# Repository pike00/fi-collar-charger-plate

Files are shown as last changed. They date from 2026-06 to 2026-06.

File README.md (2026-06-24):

---
title: "Fi collar charger plate"
description: "A 3D-printed Decora outlet faceplate that holds two Fi Series 3 dog-collar charging bases in flanking cradles, charges the collars in place, keeps the outlet usable, and swallows t…"
date: 2026-06-10
version: v2.2
tags: [pet, mounting, electronics]
material: PETG / PLA
print: { layer_height: 0.2mm, infill: 25%, supports: false }
license: CC-BY-NC-4.0
showcase: false
source: private
---

# Fi collar charger plate

A 3D-printed **Decora outlet faceplate** that holds **two Fi Series 3 dog-collar
charging bases** in flanking cradles, charges the collars in place, keeps the
outlet usable, and swallows the cables inside the cradle bodies.

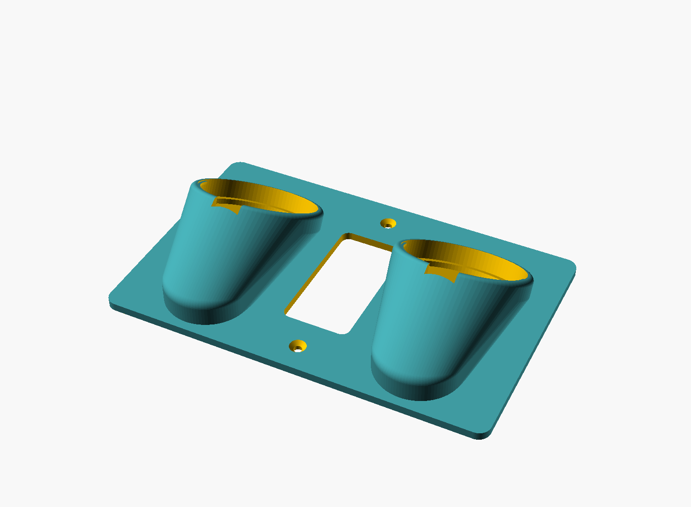
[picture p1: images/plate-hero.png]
hero


## What it mates with

- **Outlet:** standard single-gang **Decora / rocker** receptacle. Mounts with
  the existing two **6-32** strap screws, **3.812" (96.85 mm)** center-to-center.
  The Decora opening is left clear so the receptacle stays usable.
- **Chargers:** two round **Fi Series 3 charging bases** (the black pucks). The
  base is **magnetic** — the collar's module snaps onto the top face and is held
  by magnet while it charges. The holder grips the *base*; the base does the
  charging and collar retention. Powered by a micro-USB cable out of each base.
- **Power:** a small **USB wall brick plugs into this same outlet** (the opening
  is left clear for it — on a duplex receptacle one socket can stay free). Both
  base cables run inward to that brick, so there's no cable run down the wall.

## How it works

Each cradle is **one seamless hulled form**: a tilted cup blended smoothly into
a rounded foot pad on the plate — no flares or stuck-on boxes; the hull surface
itself is the blend. The cup leans back (`cradle_tilt`, default 30°) so the
charging face aims up-and-out; the magnetic base plus a thin lip keep everything
seated. The collar band drapes down the front.

**Geometry constraint (why 30° and why the cup floats):** a wide puck tilted
near a wall would physically extend *behind* the wall plane — at 45° a 67 mm
puck needs its rear edge ~22 mm inside the wall. The model auto-derives
`cup_lift` from the tilt so the entire recess clears the wall plane (+1 mm).
Versions before v1.6 missed this; their recesses were sheared off at the wall
and a real puck could never have seated. Raising `cradle_tilt` is allowed but
automatically grows the prow (45° → ~62 mm stick-out; 30° → ~48 mm).

**Retaining lip:** a thin inward **lip** (`lip_in`, default 1.3 mm) on the lower
half of the recess rim, with a gap at the bottom aligned with the cable slot.
Drop the puck in from the top; the lip catches its rim so it can't slide out.

**Cables / where they go:** the puck's micro-USB plug rides down a **slot in the
cup's lower wall** (`notch_w`) as the puck seats. The slot continues inside the
cradle body into a **hidden cable cavity** (`cav_*`) — coil the excess in there.
The tail exits a small **mouth on the cradle's inner side** and runs along a
shallow **groove** in the plate face to the USB brick in the outlet. Use a short
cable (6–12") so the cavity isn't overstuffed.

The mounting face is dead flat (everything is clipped at the wall plane), so it
sits flush on the outlet.

## Dimensions are ESTIMATED (Fi doesn't publish them)

Fi publishes no specs for the bare base puck — only the retail box
(170 × 110 × 63 mm). The values below are an **estimate** from product photos +
the box size, set at the top of
[src/fi-collar-charger-plate.scad](src/fi-collar-charger-plate.scad). The fit is
forgiving (magnetic retention + generous clearance), but a 20-second ruler check
of the real puck lets you tighten it to a true snug fit:

| Parameter | Meaning | Value (estimate) |
|---|---|---|
| `base_dia` | outer diameter of the round Fi base | **67 mm — estimate**  |
| `base_thick` | puck thickness / height | **13 mm — estimate**  |
| `base_clear` | radial fit clearance | 1.0 mm (generous) |
| `cradle_tilt`| base face angle from vertical | 30° (lift auto-derived) |

Re-export after editing: `just build` (or override headless, e.g.
`openscad -D 'base_dia=63' -D 'base_clear=0.5' -o out.stl src/...scad`).

## Size note (the honest trade-off)

A face-up puck held near a wall **inherently sticks out** — there is no way to
charge a collar face-up against a wall without a shelf-like protrusion, and the
wall-clearance constraint above makes the minimum protrusion a function of tilt.
At the 67 mm estimated size the plate comes out **~210 × 123 × 4 mm (8.3 × 4.8")**
and the cradles stand **~48 mm proud** at the rim front (30° tilt). Levers:

- **Smaller real `base_dia`** — quite possible; 67 mm is an estimate. Shrinks
  both the plate and the required lift.
- **Lower `cradle_tilt`** — flatter to the wall, smaller prow (magnetic
  retention means the collar stays on even at a low tilt).
- **Switch layout to stacked** (cups above the opening, not flanking) — a much
  narrower plate (~93 mm wide: cup + edge margins). This is a code change, not
  a parameter.

## Print settings (suggested — update after first print)

- Material: PETG or PLA+ (near an outlet; PETG tolerates warmth better).
- Layer height: 0.2 mm. Walls: 3+ perimeters. Infill: 15–25%. Solid model
  volume is ~280 cm³ (measured via trimesh) — the hulled cradles are chunky, so
  filament use is driven by infill; trust the slicer's estimate.
- **Orientation:** plate back (wall side) flat on the bed; cups face up. The
  hull prow is a smooth ~45–60° overhang — self-supporting. The hidden cable
  cavity ceiling bridges ~30 mm; droop in there is invisible. The cup rim's
  upper arc may want a touch of support at high `cradle_tilt`.
- Screws: reuse the outlet's existing 6-32 screws; `screw_clear`/`screw_head`
  are sized for a flat-head countersink on the front face.

## Build

```
just build      # export export/fi-collar-charger-plate.stl (high $fn)
just preview    # re-render images/*.png (needs xvfb on this headless host)
just dims       # print derived plate size / cup bore without exporting
just clean      # remove generated STL
```

BOSL2 is pulled from `~/.local/share/OpenSCAD/libraries` via `OPENSCADPATH`
(wired into the justfile).

Inspection renders: `-D section=1` slices a cup (YZ); `-D section=2` slices the
cable cavity (XZ).

## Status

**v1.6 — geometry rebuilt: each cradle is one hulled seamless form (cup + foot
pad), the cable cup is now an internal hidden cavity with an inner exit mouth,
and the wall-intersection flaw was found and fixed (`cup_lift` auto-derived so
the recess actually clears the wall; tilt default now 30°). Verified by a
3-agent adversarial audit (numeric transform recomputation + trimesh probes of
the STL + render inspection): recess clears the wall by 0.87 mm, chute→cavity
aperture 175 mm², mouth exits to open air, mesh watertight. The audit caught and
this version fixes: a lip strap bridging the cable slot (center=true cutter
bug), 0.16 mm cavity-corner membranes (pad roundover now buried in the plate),
a mouth-exit ledge, floating groove starts, and a 1 mm groove web (now 2 mm).**
Not yet printed; a ruler check of the real puck would let you tighten the fit.
See the table above.

Earlier: v1.5 flare experiment (superseded — the flare never matched the tilted
footprint and looked lumpy), v1.4 hollow-shell fix, v1.3 bins + lip, v1.2 inward
routing, v1.1 estimated dims, v1 first cut.

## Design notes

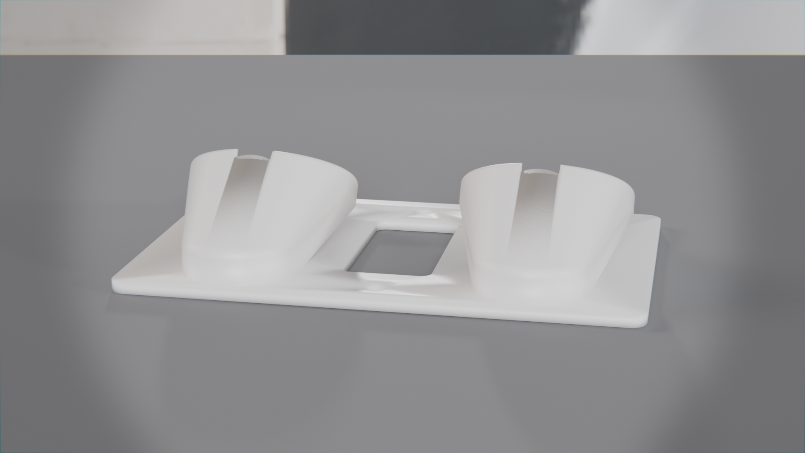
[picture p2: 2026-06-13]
images/blender-hero.png

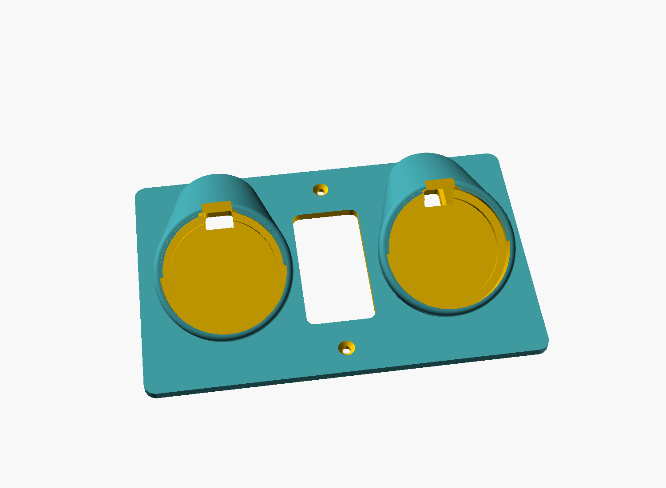
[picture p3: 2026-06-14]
images/plate-topdown.png

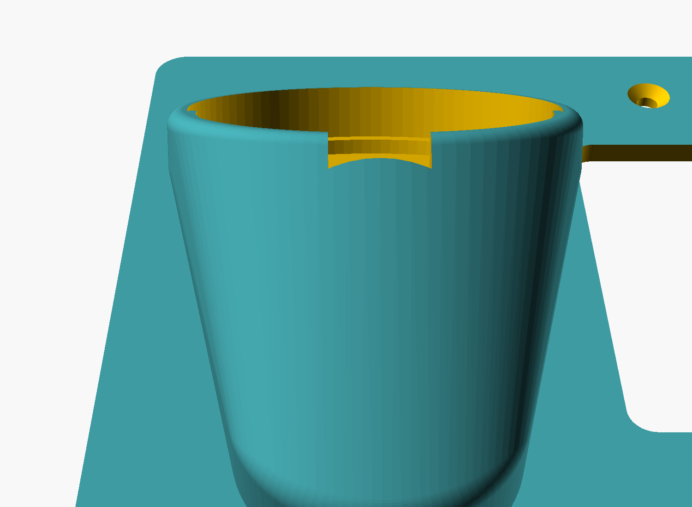
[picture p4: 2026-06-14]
images/zoom-cup.png

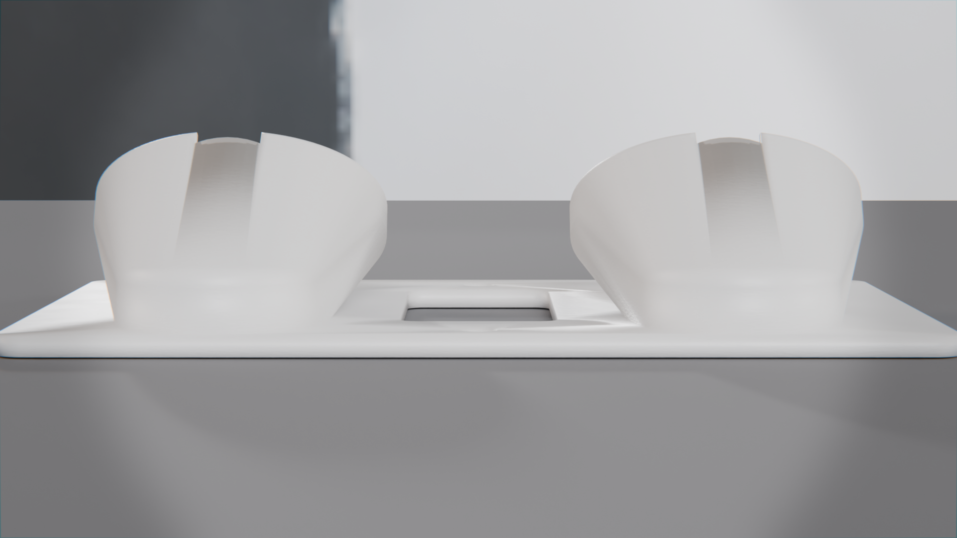
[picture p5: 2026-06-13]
images/blender-front.png

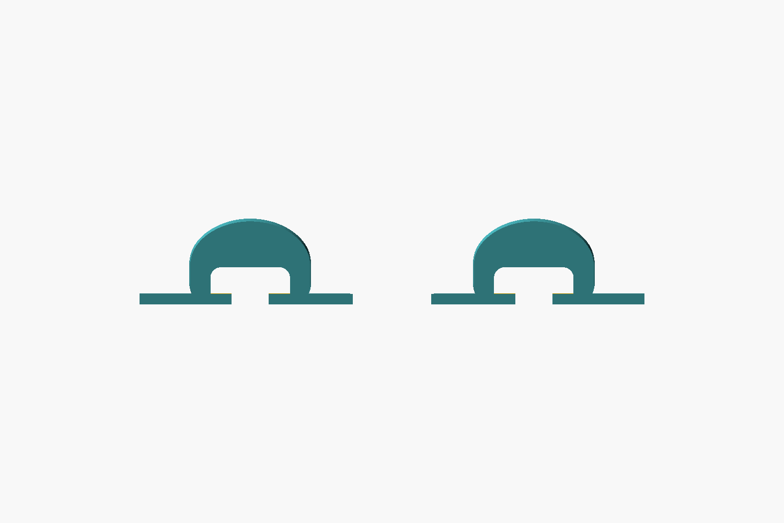
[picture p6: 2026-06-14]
images/section-cavity.png

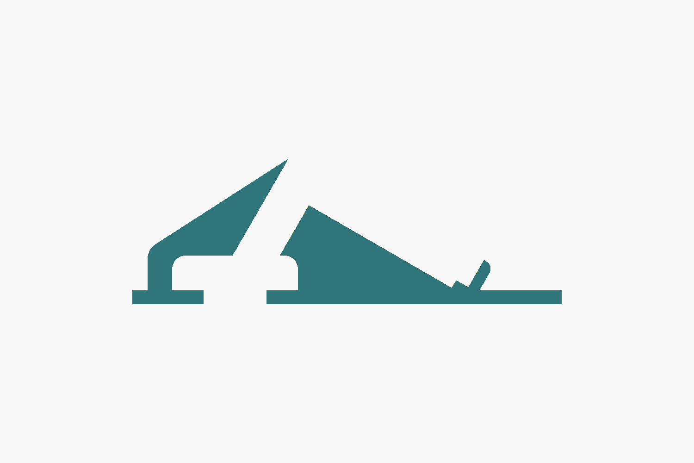
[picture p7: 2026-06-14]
images/section-cup.png

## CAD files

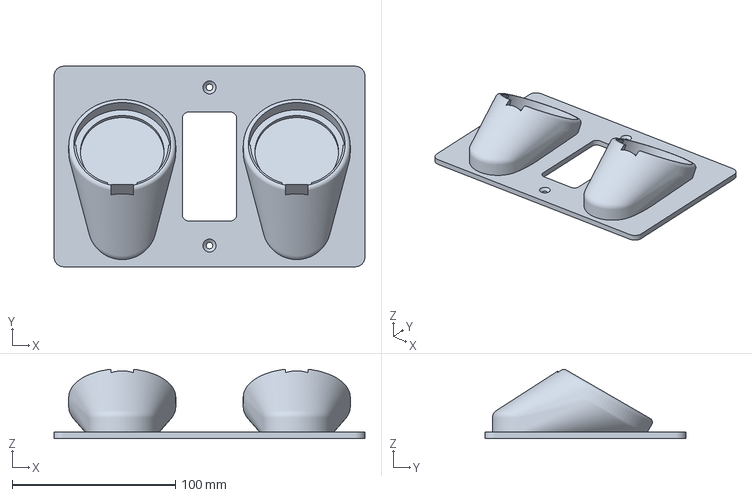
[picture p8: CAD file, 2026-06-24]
export/fi-collar-charger-plate.3mf
190.5 x 122.8 x 42.5 mm

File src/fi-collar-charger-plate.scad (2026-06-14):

// =============================================================================
// Fi collar charger plate — flanking cradles on a Decora outlet faceplate
// -----------------------------------------------------------------------------
// Mounts to a standard single-gang DECORA receptacle using the two 6-32 strap
// screws (3.812" / 96.85 mm vertical c-c). The Decora opening stays clear so a
// small USB brick can plug into the outlet. Two cradles flank the opening; each
// is ONE seamless hulled form: a tilted cup (charging face up-and-out) blending
// smoothly into a rounded base pad on the plate. The Fi base puck drops into the
// cup and a thin lip captures its rim. The puck's cable rides down a slot in
// the cup's lower wall into a HOLLOW CAVITY inside the cradle body, then exits
// through a slot in the plate BACK FACE into the wall box — no groove across
// the plate front, no sharp inner-mouth bend (~30° curve max from cup axis).
//
// The holder grips the BASE; the base (magnetic) does the charging + collar
// retention. Only fit-critical inputs are the puck's own dimensions.
//
// Build:   just build        (STL)     |  Preview: just preview  (PNG)
// Override any param headless:  openscad -D 'base_dia=58.2' -o out.stl <src>
// Inspect: -D section=1 (YZ slice through a cup), -D section=2 (XZ slice
//          through the cable cavity).
// =============================================================================

include <BOSL2/std.scad>

/* [Fi base puck — measured with calipers] */
// Outer diameter of the round Fi Series 3 base puck (mm). Measured: 58.2 mm.
base_dia      = 58.2;
// Puck thickness / height (mm). Measured: 11 mm.
base_thick    = 11;

/* [Fit] */
// Radial clearance around the puck (mm). Tightened to 0.5 now that we have
// a real measurement; adjust ±0.2 for printer tolerance.
base_clear    = 0.5;

/* [Cradle] */
// Base FACE angle from VERTICAL: 0 = faces straight out from wall, 90 = faces
// straight up. NOTE: tilting a wide puck near a wall forces the cup outward —
// the model auto-derives `cup_lift` so the recess fully clears the wall plane
// (at 45 deg the prow would stick out ~62 mm; 30 deg lands at ~48 mm).
cradle_tilt   = 30;      // deg
// How deep the puck sits into the cup. Keep < base_thick so the charging face
// stays exposed for the collar.
cup_depth     = 9;       // mm
cradle_wall   = 3.2;     // mm  cup side wall
cup_round     = 2.5;     // mm  rounding on the cup body edges (soft rim)

/* [Cup ledge — ring that the puck rim rests on; cup interior is open above and below] */
ledge_h       = 2.5;     // mm  ledge ring height
ledge_w       = 4.0;     // mm  ledge ring radial width (inward from cup inner wall)

/* [Base pad — the cradle's foot; the hull from cup to pad IS the seamless blend] */
pad_d         = 42;      // mm  pad diameter on the plate
pad_y         = -36;     // mm  pad center, below the cup (toward plate bottom)
pad_h         = 14;      // mm  pad height
pad_round     = 5;       // mm  pad edge rounding

/* [Charger retaining lip — thin catch over the puck rim] */
lip_in        = 1.3;     // mm  inward overhang over the puck rim
lip_h         = 1.4;     // mm  lip thickness (down from the cup rim)
lip_gap_w     = 18;      // mm  gap in the lip at the bottom (puck/cable slot)

/* [Cable — slot down cup wall into cavity, exits through plate BACK face] */
notch_w       = 14;      // mm  slot width in the cup's lower wall (plug rides down)
cav_w         = 30;      // mm  internal cable cavity width  (x)
cav_len       = 36;      // mm  internal cable cavity length (y)
cav_h         = 10;      // mm  cavity height above the plate front
mouth_w       = 14;      // mm  back-plate exit slot width (x); cable exits rearward

/* [Decora plate] */
plate_th      = 4.0;     // mm  faceplate slab thickness
plate_corner  = 6;       // mm  rounded outer corners
opening_w     = 33.3;    // mm  Decora opening width  (1.31")
opening_h     = 66.8;    // mm  Decora opening height (2.63")
opening_r     = 4;       // mm  opening corner radius
screw_spacing = 96.85;   // mm  6-32 strap screw c-c, vertical (3.812")
screw_clear   = 4.0;     // mm  6-32 shank clearance hole
screw_head    = 8.0;     // mm  countersink head diameter (flat-head)
edge_margin   = 9;       // mm  plate material around the cradles/screws
gap           = 4;       // mm  clearance between Decora opening and a cradle

/* [Quality] */
$fn           = 48;      // bump to 96+ for the final export

// ---- derived ----------------------------------------------------------------
cup_id        = base_dia + 2*base_clear;          // cup inner bore
cup_od        = cup_id + 2*cradle_wall;           // cup outer
cup_h         = cup_depth + ledge_h;              // cup total height
// Lift the cup out along its own axis until the ledge's rear edge sits
// in FRONT of the wall plane (+1 mm along the axis, ~0.87 mm normal to the
// wall). Without this, a tilted wide puck physically intersects the wall — the
// flaw in every version before v1.6.
cup_lift      = max(0, (cup_id/2)*tan(cradle_tilt) - ledge_h + 1);
assert(cup_depth < base_thick,
       "cup_depth must stay below base_thick so the charging face is exposed");
off_x         = opening_w/2 + gap + cup_od/2;     // cradle center, off the midline
cav_y         = -32;                              // cavity center (y)
plate_w       = 2*(off_x + cup_od/2) + 2*edge_margin;
plate_h       = screw_spacing + 2*(screw_head/2 + edge_margin);
eps           = 0.02;

echo(str("== Fi collar charger plate =="));
echo(str("  cup bore (puck+clear): ", cup_id, " mm   cup outer: ", cup_od, " mm"));
echo(str("  cup_lift: ", cup_lift, " mm (auto, keeps recess in front of wall)"));
echo(str("  stick-out at rim front: ~",
         plate_th + (cup_lift + cup_h)*cos(cradle_tilt) + (cup_od/2)*sin(cradle_tilt),
         " mm proud of the wall (upper bound; rim rounding trims ~1 mm)"));
echo(str("  PLATE: ", plate_w, " x ", plate_h, " x ", plate_th, " mm",
         "  (", plate_w/25.4, " x ", plate_h/25.4, " in)"));

// ---- frames ------------------------------------------------------------------
// Cup-local tilted frame: origin at the BOTTOM CENTER of the (lifted) cup,
// +Z along the cup axis (tilted back by cradle_tilt so it aims up-and-out).
// The lift keeps the whole recess in front of the wall plane.
module in_cup_frame() {
    translate([0, 0, plate_th])
        rotate([-cradle_tilt, 0, 0])
            translate([0, 0, cup_lift])
                children();
}

// Place children at a cradle position. The local +X axis is the INNER side
// (toward the outlet); the right cradle is mirrored so its mouth also faces in.
module at_cradle(sx) {
    translate([sx*off_x, 0, 0]) {
        if (sx > 0) mirror([1, 0, 0]) children();
        else children();
    }
}

// ---- the model ----------------------------------------------------------------
module plate_blank() {
    translate([0, 0, plate_th/2])
        cuboid([plate_w, plate_h, plate_th],
               rounding = plate_corner, edges = "Z");
}

module decora_opening() {
    translate([0, 0, -eps])
        linear_extrude(plate_th + 2*eps)
            rect([opening_w, opening_h], rounding = opening_r);
}

module screw_holes() {
    for (s = [-1, 1])
        translate([0, s*screw_spacing/2, 0]) {
            translate([0, 0, -eps])
                cylinder(h = plate_th + 2*eps, d = screw_clear);
            translate([0, 0, plate_th - (screw_head-screw_clear)/2])
                cylinder(h = (screw_head-screw_clear)/2 + eps,
                         d1 = screw_clear, d2 = screw_head);
        }
}

// The whole cradle body is ONE convex hull: tilted cup blended into the base
// pad. No flares, no stuck-on boxes — the hull surface IS the seamless blend.
module cradle_solid() {
    hull() {
        in_cup_frame()
            cyl(h = cup_h, d = cup_od, rounding = cup_round, anchor = BOTTOM);
        // pad sunk by pad_round so its bottom roundover is buried in the plate:
        // at the plate face the pad presents its FULL radius, keeping ≥2 mm of
        // wall around the cable cavity corners (was a 0.16 mm membrane)
        translate([0, pad_y, plate_th - pad_round])
            cyl(h = pad_h + pad_round, d = pad_d, rounding = pad_round, anchor = BOTTOM);
    }
}

// Puck recess: full bore from the ledge upward; the center of the ledge is also
// cut so only a `ledge_w`-wide ring remains at the cup bottom. The puck rim
// sits on this ring; the cup interior is open top and bottom.
module recess_cut() {
    in_cup_frame() {
        translate([0, 0, ledge_h])
            cylinder(h = cup_depth + 8, d = cup_id);
        translate([0, 0, -eps])
            cylinder(h = ledge_h + 2*eps, d = cup_id - 2*ledge_w);
    }
}
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

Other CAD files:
export/fi-collar-charger-plate.stl

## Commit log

2026-06-10 fi-collar-charger-plate v1: parametric Decora plate, 2 flanking Fi-base cradles + cable routing
    [fi-collar-charger-plate.scad, fi-collar-charger-plate.stl]
2026-06-10 v1.1: set base dims to best estimate (67x13mm, Fi specs unpublished); note magnetic retention
    [fi-collar-charger-plate.scad, fi-collar-charger-plate.stl]
2026-06-11 v1.2: route cables inward to a USB brick in this outlet (inner notches, grooves, wind-posts for slack)
    [fi-collar-charger-plate.scad, fi-collar-charger-plate.stl]
2026-06-11 v1.3: hollow cable cup below each charger + retaining lip on each cup rim
    [fi-collar-charger-plate.scad, fi-collar-charger-plate.stl]
2026-06-11 v1.4: hollow the cradle into a proper shell (was a solid wedge with a shallow dimple)
    [fi-collar-charger-plate.scad, fi-collar-charger-plate.stl]
2026-06-11 v1.5: thinner lip + seamless molded look (chamfered rim, rounded bins, flared fillet base)
    [fi-collar-charger-plate.scad, fi-collar-charger-plate.stl]
2026-06-11 v1.6: rebuild cradles as hulled seamless forms; fix wall-intersection flaw (auto cup_lift, tilt 30); internal cable cavity + audited fixes
    3-agent adversarial audit (numeric transform recomputation, trimesh STL probes, render inspection) verified the architecture and caught: lip-gap center=true bug leaving a 0.7mm strap across the cable slot (fixed, 0/108 probes solid), 0.16mm cavity-corner membranes from the pad bottom roundover (fixed by burying the roundover in the plate, walls now 2.12mm), mouth-exit ledge, floating groove starts, 1mm groove web (now 2mm). justfile preview now regenerates all 7 images.
    [fi-collar-charger-plate.scad]
2026-06-13 v2: real puck measurements (44mm dia, 11mm thick) + cable exits through plate back
    [fi-collar-charger-plate.scad]
2026-06-13 convert measurement photos HEIC→PNG; add Blender render setup
2026-06-13 bump puck diameter to 58.2mm (re-measured); rebuild STL + renders
    [fi-collar-charger-plate.scad]
2026-06-14 v2.2: replace solid cup floor with open ledge ring; puck rim seats on ring, interior open top/bottom
    [fi-collar-charger-plate.scad]
2026-06-24 feat: showcase frontmatter, CC-BY-NC license, derived GLB+3MF
    Phase 1+2 of the prints.pikemd.com showcase pipeline: README YAML frontmatter (the showcase contract; showcase:false until curated), a CC-BY-NC-4.0 LICENSE, and centralized web GLB + manufacturing 3M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
    [fi-collar-charger-plate.3mf]
